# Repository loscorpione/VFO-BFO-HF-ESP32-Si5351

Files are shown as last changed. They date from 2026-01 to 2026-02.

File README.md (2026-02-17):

<h2 align="center">VFO/BFO con SI5351A ed ESP32</h2>

Questo progetto descrive la realizzazione di un VFO / BFO digitale
basato su ESP32 DevKit 32D e generatore di frequenza Si5351A.



Il sistema è stato progettato per applicazioni radioamatoriali,
in particolare per ricevitori HF autocostruiti, ma può essere
utilizzato anche in apparati sperimentali e RTX fino a circa 160 MHz.

Caratteristiche:
- Generazione VFO e BFO indipendenti
- Gestione modi: AM, LSB, USB, CW
- Controllo AGC e attenuatore
- Pitch regolabile del BFO
- S-meter digitale con memoria di picco
- Encoder meccanici e ottici
- Display TFT a colori
- Espansione I/O tramite PCF8574
- Memorizzazione configurazioni su EEPROM 24LC32
- Firmware modulare in C++
- Funzione di calibrazione del Si5351

Architettura codice:
Il codice è strutturato in modo modulare:

- VFO_BFO → gestione frequenze
- PLL → configurazione Si5351
- bands / modes → logica operativa
- DigiOUT → uscite digitali PCF8574
- s_meter → lettura analogica
- display → interfaccia grafica
- EEPROM_manager → salvataggio configurazioni

Il firmware è sviluppato con PlatformIO su VS Code.

Questa scelta permette:
- gestione strutturata del progetto
- controllo delle librerie
- maggiore scalabilità rispetto all’Arduino IDE

⚠️ Il firmware è in continua evoluzione.

I comandi sono:
- ENCODER 1: come selettore di frequenza.
- ENCODER 2: come variazione Pitch del BFO
- STEP: per cambio frequenza (10Hz, 100Hz, 1KHz, 10KHZ) con indicazione su display.
- BAND: per la selezione della banda con indicazione su display delle bande radioamatoriali e non.
- MODE: seleziona il tipo di demodulazione, con indicazione su pin binaria.
- AGC: slow e fast
- ATT: selettore attenuatore

<h2 align="center">🎬 Video del progetto</h2>

<p align="center">
  <a href="https://youtu.be/RLuy1z0uWSg">
    
  </a>
</p>

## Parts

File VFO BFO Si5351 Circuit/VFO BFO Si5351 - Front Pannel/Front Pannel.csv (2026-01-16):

Reference | Qty | Value | DNP | Exclude from BOM | Exclude from Board | Footprint | Datasheet
D1 | 1 | LED |  |  |  | LED_THT:LED_D3.0mm | ~
H1,H2,H3,H4 | 4 | MountingHole |  | Escluso dalla DIBA |  | MountingHole:MountingHole_3.2mm_M3_DIN965 | ~
J1 | 1 | LED |  |  |  | Connector_JST:JST_EH_B2B-EH-A_1x02_P2.50mm_Vertical | ~
J2 | 1 | Optical Rotary Encoder |  |  |  | Connector_JST:JST_EH_B4B-EH-A_1x04_P2.50mm_Vertical | ~
J3 | 1 | Mecc_rotary encoder |  |  |  | Connector_PinSocket_2.54mm:PinSocket_1x05_P2.54mm_Horizontal | ~
J4 | 1 | VFO_Front_Pannel |  |  |  | Connector_PinHeader_2.54mm:PinHeader_1x20_P2.54mm_Vertical | ~
R1 | 1 | R=Vled-2/20mA |  |  |  | Resistor_THT:R_Axial_DIN0207_L6.3mm_D2.5mm_P10.16mm_Horizontal | ~
R2,R3,R4 | 3 | 10K |  |  |  | Resistor_THT:R_Axial_DIN0207_L6.3mm_D2.5mm_P10.16mm_Horizontal | ~
SW1 | 1 | RotaryEncoder_Clarifier |  |  |  | -Rotary_Encoder:RotaryEncoder_Alps_EC12E-Switch_Vertical_H20mm | ~
SW2 | 1 | SW_Band |  |  |  | Button_Switch_THT:SW_PUSH_6mm | ~
SW3 | 1 | SW_Mode |  |  |  | Button_Switch_THT:SW_PUSH_6mm | ~
SW4 | 1 | SW_AGC |  |  |  | Button_Switch_THT:SW_PUSH_6mm | ~
SW5 | 1 | SW_ATT |  |  |  | Button_Switch_THT:SW_PUSH_6mm | ~
SW6 | 1 | SW_Scan |  |  |  | Button_Switch_THT:SW_PUSH_6mm | ~
SW7 | 1 | SW_Step |  |  |  | Button_Switch_THT:SW_PUSH_6mm | ~
SW8 | 1 | SW_RTTY_CW |  |  |  | Button_Switch_THT:SW_PUSH_6mm | ~
U1 | 1 | Ili9341_Module_TFT_320x240_Touch |  |  |  | -Display_Graphic:DISPLAY_TFT_ILI9341_2.8

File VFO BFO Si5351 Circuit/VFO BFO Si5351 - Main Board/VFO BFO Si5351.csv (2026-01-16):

Reference | Qty | Value | DNP | Exclude from BOM | Exclude from Board | Footprint | Datasheet
C1,C4 | 2 | 100nF |  |  |  | Capacitor_THT:C_Rect_L7.0mm_W2.5mm_P5.00mm | ~
C2 | 1 | 220uF 16V |  |  |  | Capacitor_THT:CP_Radial_D6.3mm_P2.50mm | ~
C3 | 1 | 100uF 10V |  |  |  | Capacitor_THT:CP_Radial_D5.0mm_P2.00mm | ~
D1 | 1 | 1N4148 |  |  |  | Diode_THT:D_DO-35_SOD27_P7.62mm_Horizontal | https://assets.nexperia.com/documents/data-sheet/1N4148_1N4448.pdf
D2,D3 | 2 | 3.3V |  |  |  | Diode_THT:D_DO-35_SOD27_P7.62mm_Horizontal | https://industrial.panasonic.com/content/data/SC/ds/ds4/DZ2S03300L_E.pdf
D4 | 1 | 1N4007 |  |  |  | Diode_THT:D_DO-41_SOD81_P10.16mm_Horizontal | http://www.vishay.com/docs/88503/1n4001.pdf
H1,H2,H3,H4 | 4 | MountingHole_Pad |  | Escluso dalla DIBA |  | MountingHole:MountingHole_3.2mm_M3_DIN965_Pad_TopBottom | ~
J1 | 1 | I2C Bus |  |  |  | Connector_JST:JST_EH_B4B-EH-A_1x04_P2.50mm_Vertical | ~
J2 | 1 | Band |  |  |  | Connector_JST:JST_EH_B4B-EH-A_1x04_P2.50mm_Vertical | ~
J3 | 1 | Mode |  |  |  | Connector_JST:JST_EH_B3B-EH-A_1x03_P2.50mm_Vertical | ~
J4 | 1 | AGC |  |  |  | Connector_JST:JST_EH_B2B-EH-A_1x02_P2.50mm_Vertical | ~
J5 | 1 | ATT |  |  |  | Connector_JST:JST_EH_B2B-EH-A_1x02_P2.50mm_Vertical | ~
J6 | 1 | BFO |  |  |  | Connector_JST:JST_EH_B2B-EH-A_1x02_P2.50mm_Vertical | ~
J7 | 1 | TX |  |  |  | Connector_JST:JST_EH_B2B-EH-A_1x02_P2.50mm_Vertical | ~
J8 | 1 | IN RTTY |  |  |  | Connector_JST:JST_EH_B2B-EH-A_1x02_P2.50mm_Vertical | ~
J9 | 1 | IN S_meter |  |  |  | Connector_JST:JST_EH_B2B-EH-A_1x02_P2.50mm_Vertical | ~
J10 | 1 | VIN +12V |  |  |  | Connector_JST:JST_EH_B2B-EH-A_1x02_P2.50mm_Vertical | ~
J11 | 1 | GND +5V +9V +12 |  |  |  | Connector_JST:JST_EH_B4B-EH-A_1x04_P2.50mm_Vertical | ~
J12 | 1 | VFO_Front_Pannel |  |  |  | Connector_PinHeader_2.54mm:PinHeader_1x20_P2.54mm_Vertical | ~
M1 | 1 | Si5351A module |  |  |  | -Periferial_Module:si5351a_Module
R1,R3 | 2 | 1K |  |  |  | Resistor_THT:R_Axial_DIN0207_L6.3mm_D2.5mm_P10.16mm_Horizontal | ~
RN1 | 1 | 10Kx8 |  |  |  | Resistor_THT:R_Array_SIP9 | http://www.vishay.com/docs/31509/csc.pdf
U1 | 1 | ESP32-DEVKITC-32D |  |  |  | -ESP32_Module:MODULE_ESP32-DEVKITC-32D
U2 | 1 | PCF8574AP |  |  |  | Package_DIP:DIP-16_W7.62mm | http://www.nxp.com/docs/en/data-sheet/PCF8574_PCF8574A.pdf
U3 | 1 | LM7809 |  |  |  | Package_TO_SOT_THT:TO-220-3_Vertical | https://www.onsemi.cn/PowerSolutions/document/MC7800-D.PDF
U4 | 1 | LM7805 |  |  |  | Package_TO_SOT_THT:TO-220-3_Vertical | https://www.onsemi.cn/PowerSolutions/document/MC7800-D.PDF
U5 | 1 | 24LC32 |  |  |  | Package_DIP:DIP-8_W7.62mm | http://ww1.microchip.com/downloads/en/DeviceDoc/21072G.pdf

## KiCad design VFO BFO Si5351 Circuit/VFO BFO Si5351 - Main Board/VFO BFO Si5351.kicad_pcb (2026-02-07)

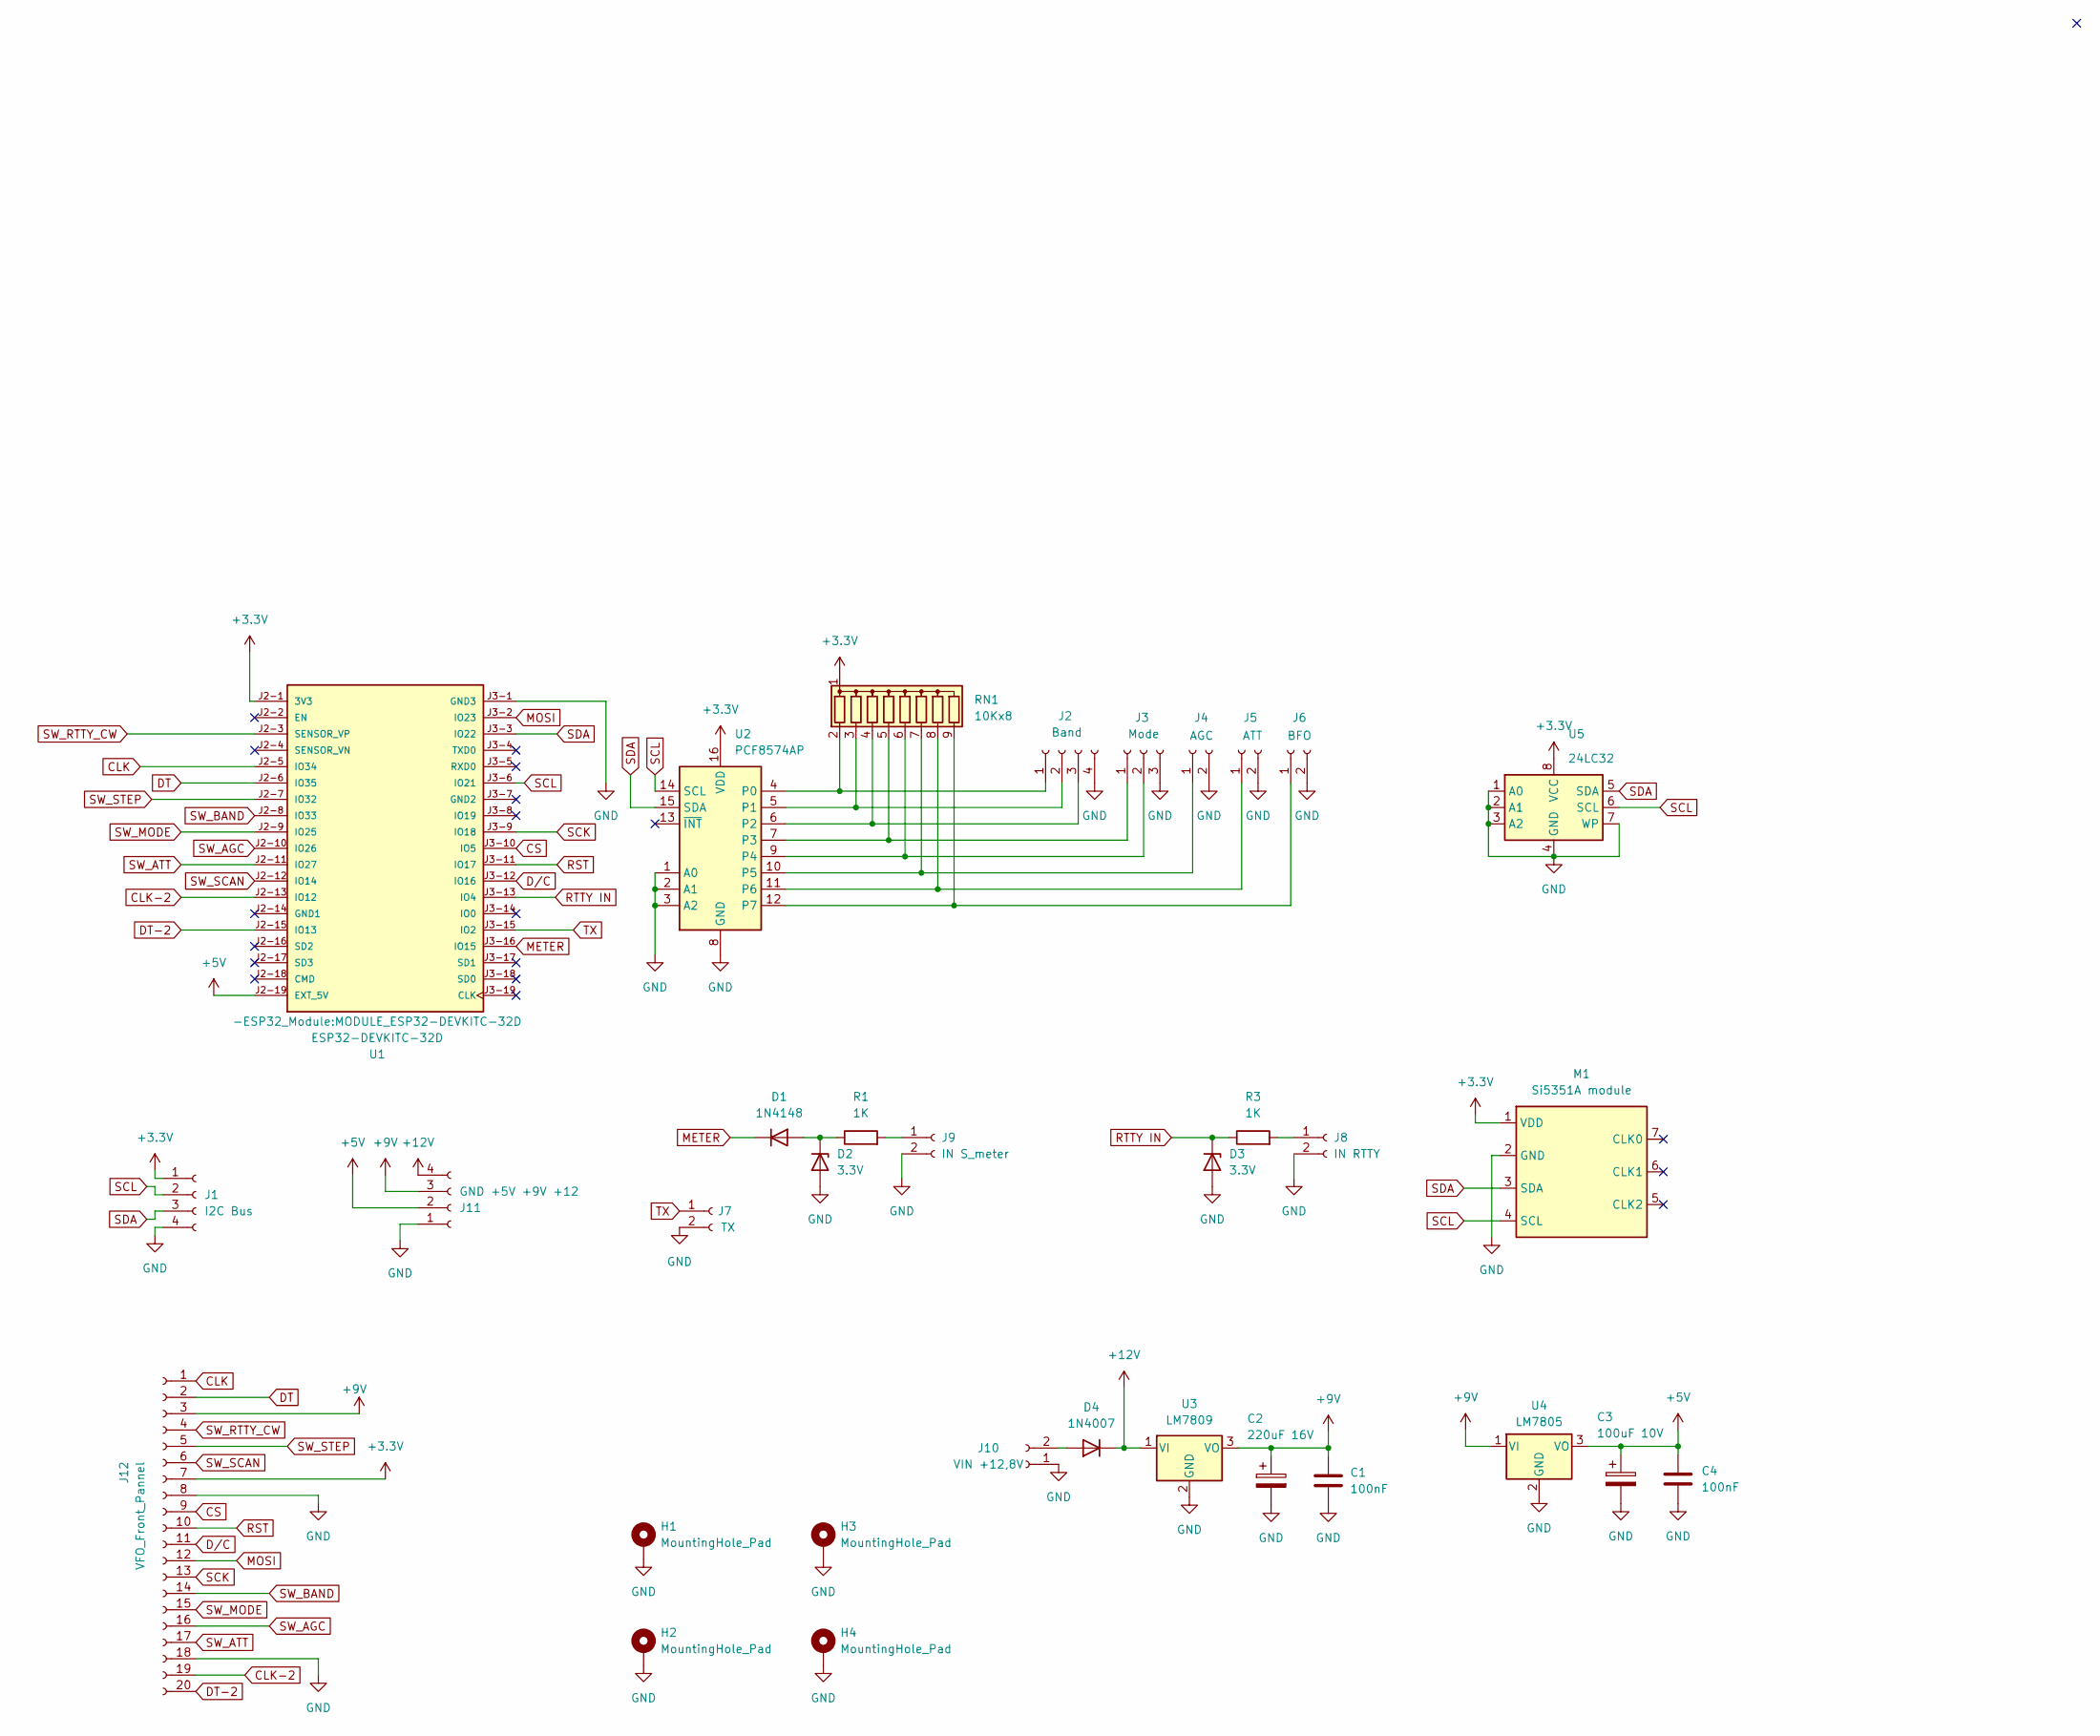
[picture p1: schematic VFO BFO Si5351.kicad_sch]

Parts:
C1, C4: 100nF; C_Rect_L7.0mm_W2.5mm_P5.00mm
C2: 220uF 16V; CP_Radial_D6.3mm_P2.50mm
C3: 100uF 10V; CP_Radial_D5.0mm_P2.00mm
D1: 1N4148; D_DO-35_SOD27_P7.62mm_Horizontal
D2, D3: 3.3V; D_DO-35_SOD27_P7.62mm_Horizontal
D4: 1N4007; D_DO-41_SOD81_P10.16mm_Horizontal
H1, H2, H3, H4: MountingHole_Pad; MountingHole_3.2mm_M3_DIN965_Pad_TopBottom
J1: I2C Bus; JST_EH_B4B-EH-A_1x04_P2.50mm_Vertical
J2: Band; JST_EH_B4B-EH-A_1x04_P2.50mm_Vertical
J3: Mode; JST_EH_B3B-EH-A_1x03_P2.50mm_Vertical
J4: AGC; JST_EH_B2B-EH-A_1x02_P2.50mm_Vertical
J5: ATT; JST_EH_B2B-EH-A_1x02_P2.50mm_Vertical
J6: BFO; JST_EH_B2B-EH-A_1x02_P2.50mm_Vertical
J7: TX; JST_EH_B2B-EH-A_1x02_P2.50mm_Vertical
J8: IN RTTY; JST_EH_B2B-EH-A_1x02_P2.50mm_Vertical
J9: IN S_meter; JST_EH_B2B-EH-A_1x02_P2.50mm_Vertical
J10: VIN +12,8V; JST_EH_B2B-EH-A_1x02_P2.50mm_Vertical
J11: GND +5V +9V +12; JST_EH_B4B-EH-A_1x04_P2.50mm_Vertical
J12: VFO_Front_Pannel; PinHeader_1x20_P2.54mm_Vertical
M1: Si5351A module; si5351a_Module
R1, R3: 1K; R_Axial_DIN0207_L6.3mm_D2.5mm_P10.16mm_Horizontal
RN1: 10Kx8; R_Array_SIP9
U1: ESP32-DEVKITC-32D; MODULE_ESP32-DEVKITC-32D; PARTREV V4
U2: PCF8574AP; DIP-16_W7.62mm
U3: LM7809; TO-220-3_Vertical
U4: LM7805; TO-220-3_Vertical
U5: 24LC32; DIP-8_W7.62mm

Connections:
+3.3V: J1.1, J12.7, M1.1 (VDD), RN1.1 (common), U1.J2-1 (3V3), U2.16 (VDD), U5.8 (VCC)
+5V: C3.1, C4.1, J11.2, U1.J2-19 (EXT_5V), U4.3 (VO)
+9V: C1.1, C2.1, J11.3, J12.3, U3.3 (VO), U4.1 (VI)
+12V: D4.1 (K), J11.4, U3.1 (VI)
CLK: J12.1, U1.J2-5 (IO34)
CLK-2: J12.19, U1.J2-13 (IO12)
CS: J12.9, U1.J3-10 (IO5)
DT: J12.2, U1.J2-6 (IO35)
DT-2: J12.20, U1.J2-15 (IO13)
D/C: J12.11, U1.J3-12 (IO16)
GND: C1.2, C2.2, C3.2, C4.2, D2.2 (A), D3.2 (A), H1.1, H2.1, H3.1, H4.1, J1.4, J2.4, J3.3, J4.2, J5.2, J6.2, J7.2, J8.2, J9.2, J10.1, J11.1, J12.8, J12.18, M1.2 (GND), U1.J3-1 (GND3), U2.1 (A0), U2.2 (A1), U2.3 (A2), U2.8 (GND), U3.2 (GND), U4.2 (GND), U5.1 (A0), U5.2 (A1), U5.3 (A2), U5.4 (GND), U5.7 (WP)
METER: D1.1 (K), U1.J3-16 (IO15)
MOSI: J12.12, U1.J3-2 (IO23)
unnamed: D1.2 (A), D2.1 (K), R1.1
unnamed: D4.2 (A), J10.2
unnamed: J2.1, RN1.2 (R1), U2.4 (P0)
unnamed: J2.2, RN1.3 (R2), U2.5 (P1)
unnamed: J2.3, RN1.4 (R3), U2.6 (P2)
unnamed: J3.1, RN1.5 (R4), U2.7 (P3)
unnamed: J3.2, RN1.6 (R5), U2.9 (P4)
unnamed: J4.1, RN1.7 (R6), U2.10 (P5)
unnamed: J5.1, RN1.8 (R7), U2.11 (P6)
unnamed: J6.1, RN1.9 (R8), U2.12 (P7)
unnamed: J8.1, R3.2
unnamed: J9.1, R1.2
RST: J12.10, U1.J3-11 (IO17)
RTTY IN: D3.1 (K), R3.1, U1.J3-13 (IO4)
SCK: J12.13, U1.J3-9 (IO18)
SCL: J1.2, M1.4 (SCL), U1.J3-6 (IO21), U2.14 (SCL), U5.6 (SCL)
SDA: J1.3, M1.3 (SDA), U1.J3-3 (IO22), U2.15 (SDA), U5.5 (SDA)
SW_AGC: J12.16, U1.J2-10 (IO26)
SW_ATT: J12.17, U1.J2-11 (IO27)
SW_BAND: J12.14, U1.J2-8 (IO33)
SW_MODE: J12.15, U1.J2-9 (IO25)
SW_RTTY_CW: J12.4, U1.J2-3 (SENSOR_VP)
SW_SCAN: J12.6, U1.J2-12 (IO14)
SW_STEP: J12.5, U1.J2-7 (IO32)
TX: J7.1, U1.J3-15 (IO2)

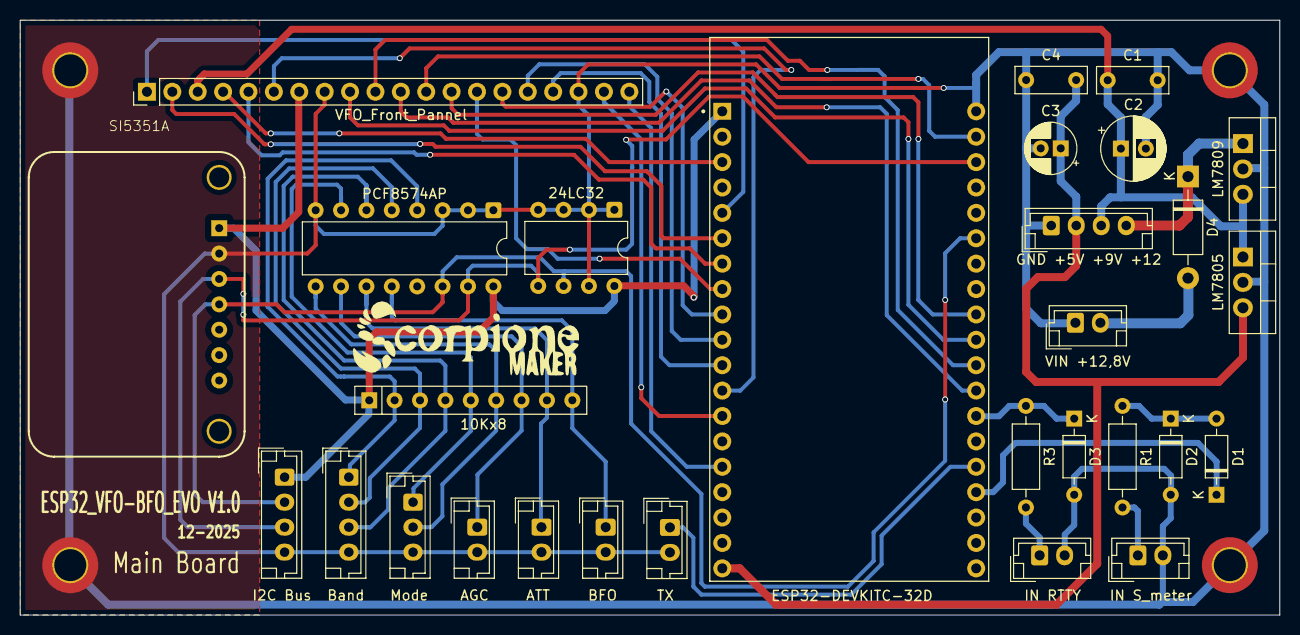
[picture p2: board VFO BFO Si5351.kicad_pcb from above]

Board: 2 copper layers, 126.0 x 59.5 mm, 33 parts (0 on the bottom side), 38 nets.

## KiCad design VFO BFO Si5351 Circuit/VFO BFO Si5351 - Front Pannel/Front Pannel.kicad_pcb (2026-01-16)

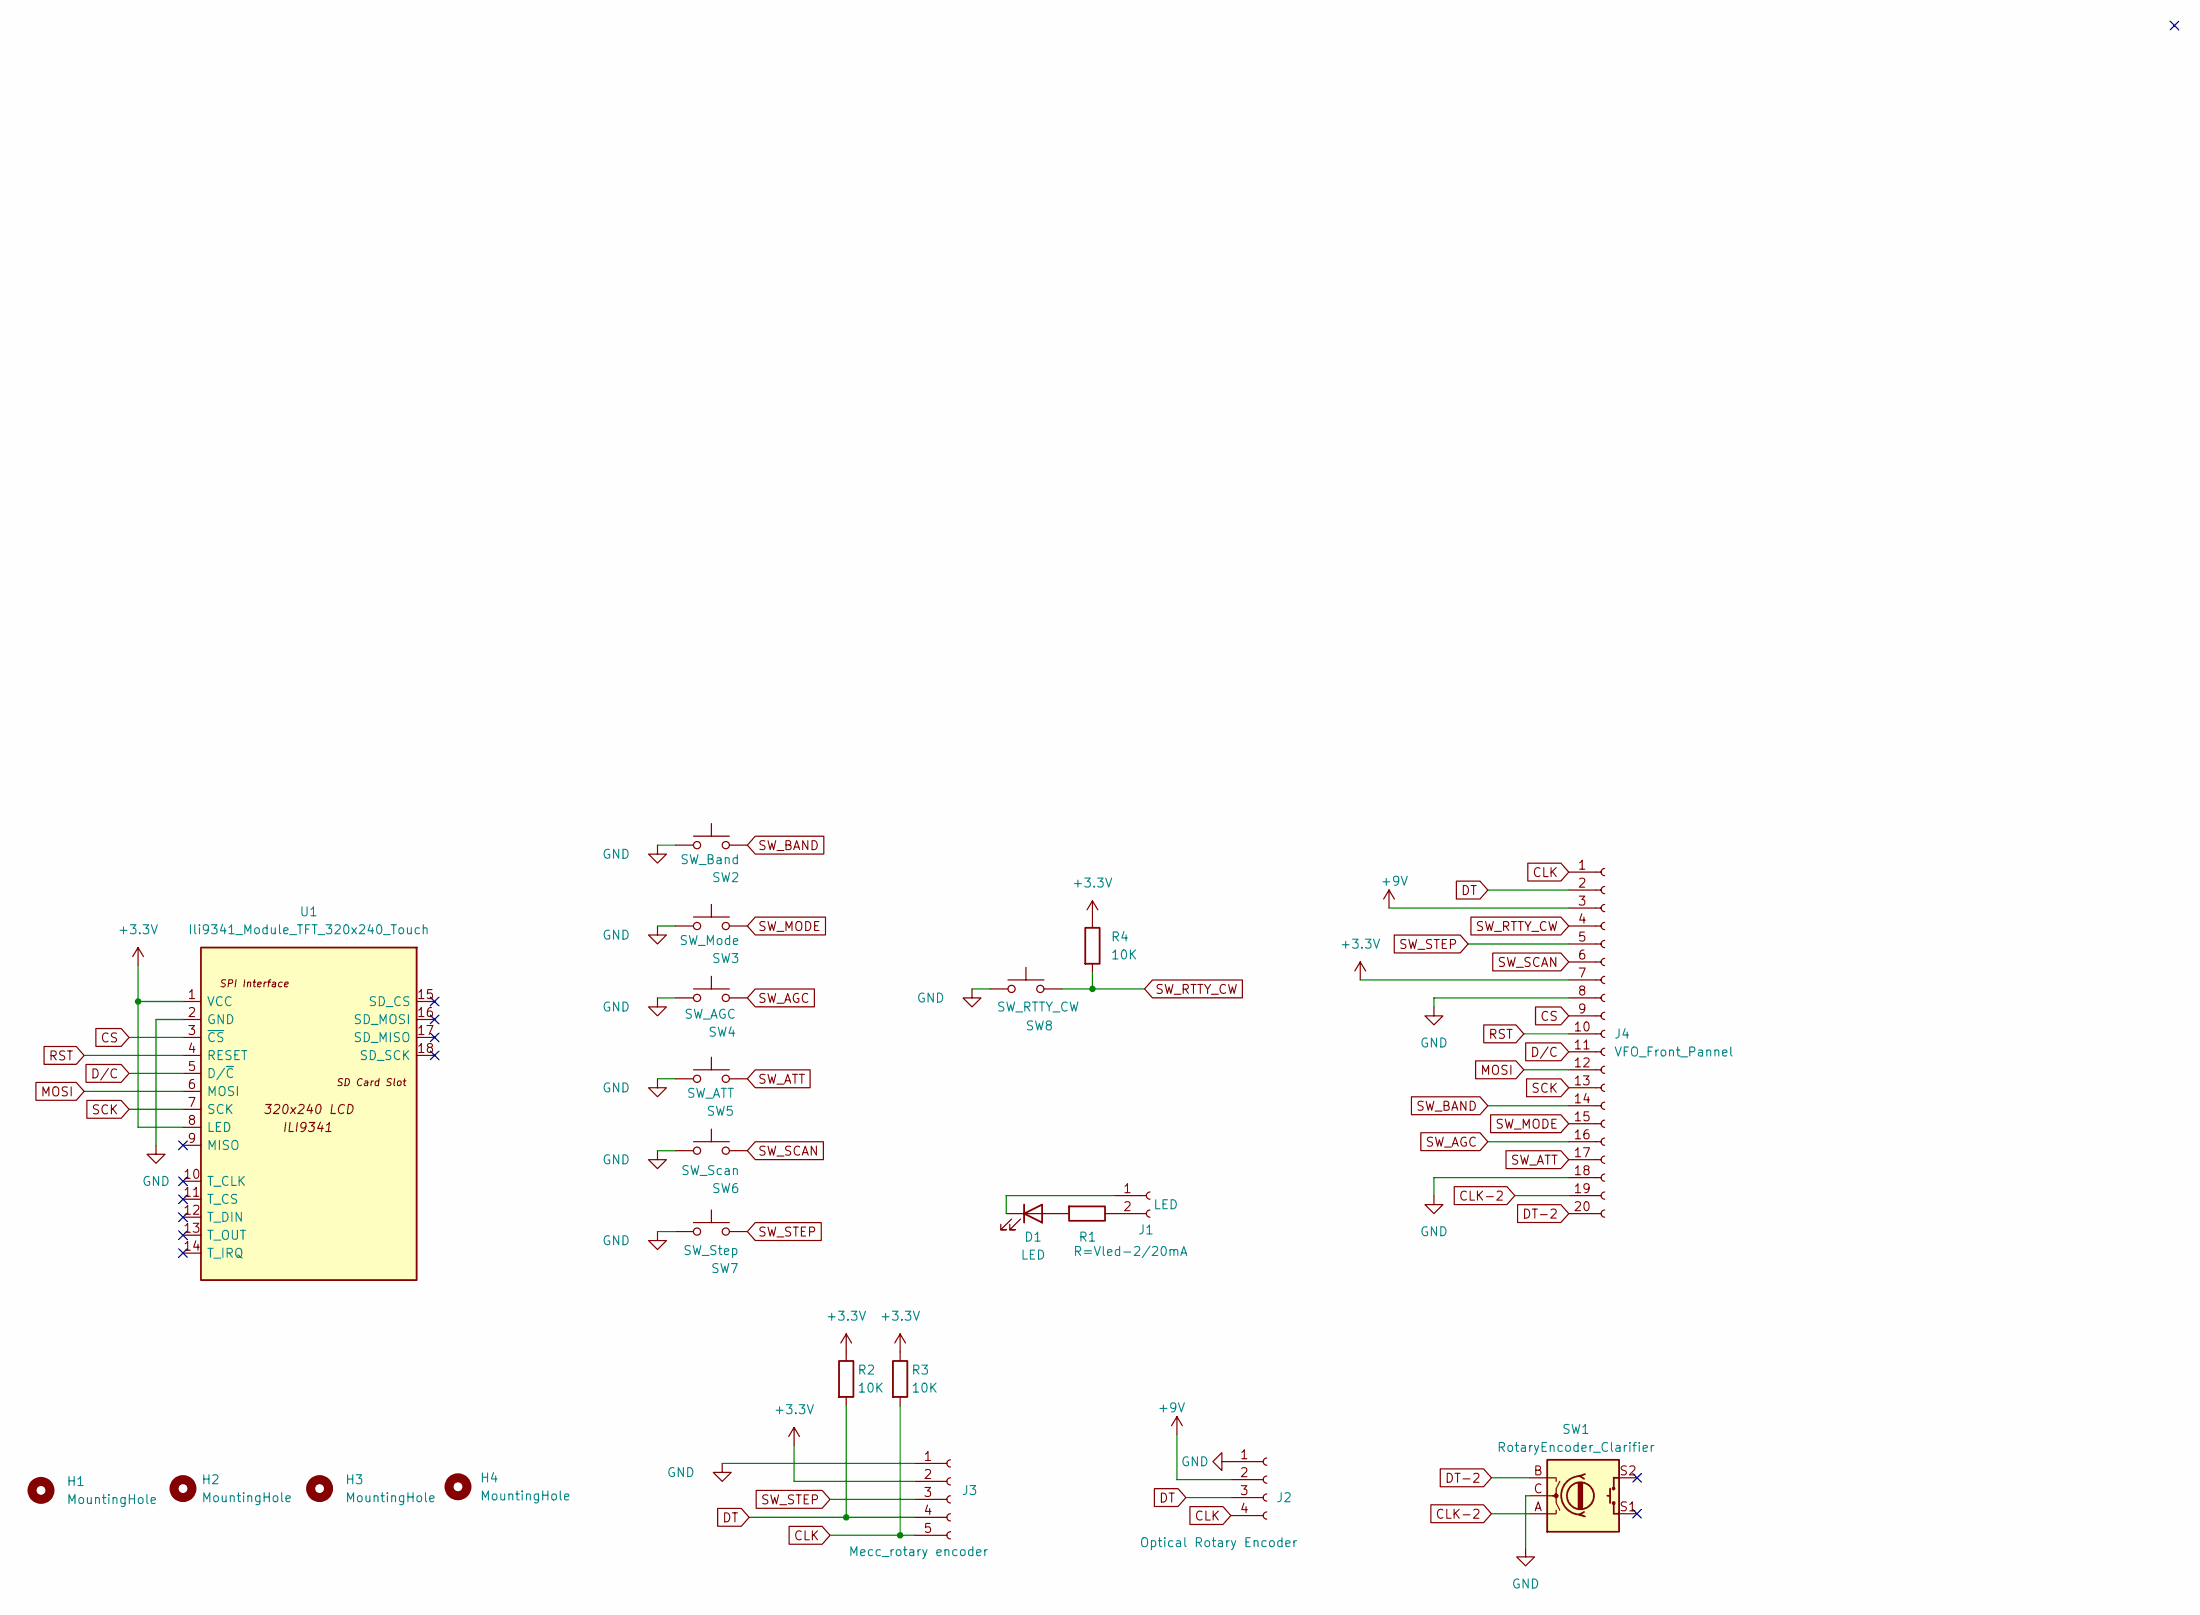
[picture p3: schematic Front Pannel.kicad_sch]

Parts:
D1: LED; LED_D3.0mm
H1, H2, H3, H4: MountingHole; MountingHole_3.2mm_M3_DIN965
J1: LED; JST_EH_B2B-EH-A_1x02_P2.50mm_Vertical
J2: Optical Rotary Encoder; JST_EH_B4B-EH-A_1x04_P2.50mm_Vertical
J3: Mecc_rotary encoder; PinSocket_1x05_P2.54mm_Horizontal
J4: VFO_Front_Pannel; PinHeader_1x20_P2.54mm_Vertical
R1: R=Vled-2/20mA; R_Axial_DIN0207_L6.3mm_D2.5mm_P10.16mm_Horizontal
R2, R3, R4: 10K; R_Axial_DIN0207_L6.3mm_D2.5mm_P10.16mm_Horizontal
SW1: RotaryEncoder_Clarifier; RotaryEncoder_Alps_EC12E-Switch_Vertical_H20mm
SW2: SW_Band; SW_PUSH_6mm
SW3: SW_Mode; SW_PUSH_6mm
SW4: SW_AGC; SW_PUSH_6mm
SW5: SW_ATT; SW_PUSH_6mm
SW6: SW_Scan; SW_PUSH_6mm
SW7: SW_Step; SW_PUSH_6mm
SW8: SW_RTTY_CW; SW_PUSH_6mm
U1: Ili9341_Module_TFT_320x240_Touch; DISPLAY_TFT_ILI9341_2.8

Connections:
+3.3V: J3.2, J4.7, R2.1, R3.1, R4.1, U1.1 (VCC), U1.8 (LED)
+9V: J2.2, J4.3
CLK: J2.4, J3.5, J4.1, R3.2
CLK-2: J4.19, SW1.A
CS: J4.9, U1.3 (~CS)
DT: J2.3, J3.4, J4.2, R2.2
DT-2: J4.20, SW1.B
D/C: J4.11, U1.5 (D/~C)
GND: J2.1, J3.1, J4.8, J4.18, SW1.C, SW2.1, SW3.1, SW4.1, SW5.1, SW6.1, SW7.1, SW8.1, U1.2 (GND)
MOSI: J4.12, U1.6 (MOSI)
unnamed: D1.2 (A), R1.2
unnamed: D1.1 (K), J1.1
unnamed: J1.2, R1.1
RST: J4.10, U1.4 (RESET)
SCK: J4.13, U1.7 (SCK)
SW_AGC: J4.16, SW4.2
SW_ATT: J4.17, SW5.2
SW_BAND: J4.14, SW2.2
SW_MODE: J4.15, SW3.2
SW_RTTY_CW: J4.4, R4.2, SW8.2
SW_SCAN: J4.6, SW6.2
SW_STEP: J3.3, J4.5, SW7.2

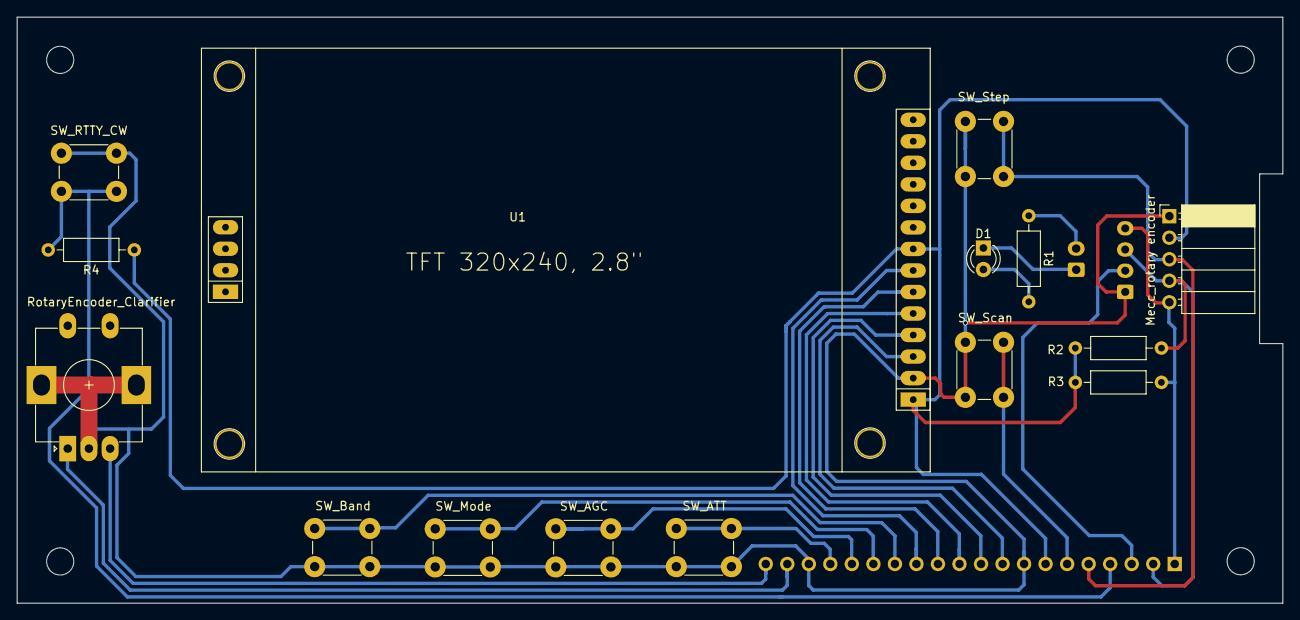
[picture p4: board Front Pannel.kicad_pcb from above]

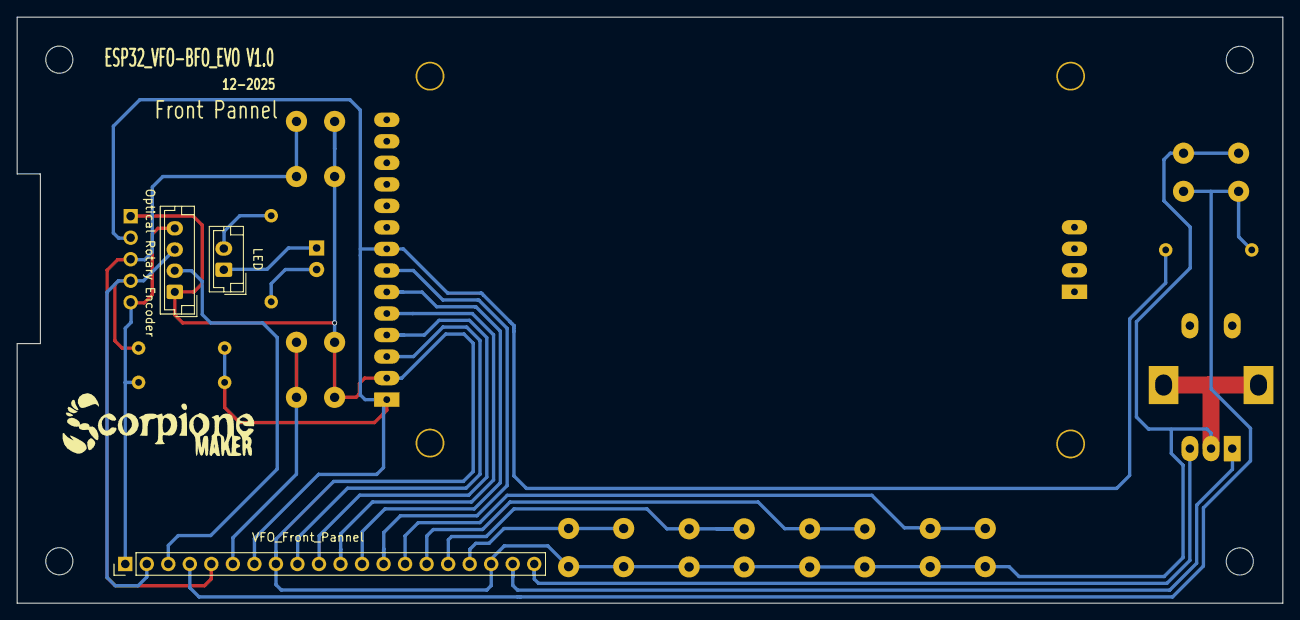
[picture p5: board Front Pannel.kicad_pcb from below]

Board: 2 copper layers, 149.4 x 69.2 mm, 22 parts (3 on the bottom side), 22 nets.

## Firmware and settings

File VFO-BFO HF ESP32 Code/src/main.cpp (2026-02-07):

#include <Arduino.h>
#include "config.h"
#include "display.h"
#include "VFO_BFO.h"
#include "PLL.h"
#include "bands.h"
#include "modes.h"
#include "s_meter.h"
#include "DigiOUT.h" 
#include "functions.h"
#include "EEPROM_manager.h"

void handleSerialCommands();
void calibrateSI5351(long calibration_factor); // Dichiarazione

// Variabile per calibrazione - AGGIUNGI
int32_t currentCalibration = 0;

// Variabili globali
unsigned long vfoFrequency = 7000000 + IF_FREQUENCY;
unsigned long displayedFrequency = 7000000;
unsigned long step = 1000;
unsigned long minFreq = 1000000;
unsigned long maxFreq = 30000000;

// Variabili per debounce
unsigned long lastEncoderRead = 0;
const int encoderReadInterval = 10;
unsigned long lastButtonPress = 0;
unsigned long lastBandButtonPress = 0;
unsigned long lastModeButtonPress = 0;

bool buttonPressed = false;
bool bandButtonPressed = false;
bool modeButtonPressed = false;

// Variabili encoder
int lastEncoded = 0;
int encoderCount = 0;

// Funzione per gestire comandi seriali
void handleSerialCommands() {
    if (Serial.available() > 0) {
        String command = Serial.readStringUntil('\n');
        command.trim();
        
        if (command.startsWith("CAL ")) {
            // Comando: CAL <valore>
            String valueStr = command.substring(4);
            long calValue = valueStr.toInt();
            
            calibrateSI5351(calValue);
            eepromManager.saveCalibration(calValue);
            currentCalibration = calValue;
            
            Serial.print("Calibrazione applicata e salvata: ");
            Serial.println(calValue);
            
        } else if (command == "CAL_READ") {
            // Legge calibrazione corrente
            Serial.print("Calibrazione corrente: ");
            Serial.println(currentCalibration);
            
        } else if (command == "CAL_RESET") {
            // Resetta calibrazione
            calibrateSI5351(0);
            eepromManager.saveCalibration(0);
            currentCalibration = 0;
            Serial.println("Calibrazione resettata a 0");
            
        } else if (command == "HELP") {
            // Mostra aiuto
            Serial.println("Comandi calibrazione SI5351:");
            Serial.println("CAL <valore>  - Imposta calibrazione (es: CAL 1250)");
            Serial.println("CAL_READ      - Legge calibrazione corrente");
            Serial.println("CAL_RESET     - Resetta calibrazione a 0");
            Serial.println("HELP          - Mostra questo aiuto");
            Serial.println("INFO          - Informazioni sistema");
            
        } else if (command == "INFO") {
            // Informazioni sistema
            Serial.println("=== VFO-BFO Receiver ===");
            Serial.print("Frequenza: ");
            Serial.print(displayedFrequency);
            Serial.println(" Hz");
            Serial.print("Modalità: ");
            Serial.println(modeNames[currentMode]);
            Serial.print("Step: ");
            Serial.println(step);
            Serial.print("Calibrazione SI5351: ");
            Serial.println(currentCalibration);
            Serial.print("BFO: ");
            Serial.println(bfoEnabled ? "ON" : "OFF");
            if (bfoEnabled) {
                Serial.print("Frequenza BFO: ");
                Serial.println(bfoFrequency);
            }
        }
    }
}

void setup() {
  Serial.begin(115200);
  delay(1000);

/*   //**********************************************************
  // // === DIAGNOSTICA I2C ===
  Serial.println("\n=== DIAGNOSTICA I2C ===");
  Wire.begin(I2C_SDA, I2C_SCL);
  Wire.setClock(100000); // 100kHz
  delay(100);
  
  // Scansiona tutto il bus I2C
  byte error, address;
  int nDevices = 0;
  
  Serial.println("Scansione bus I2C...");
  for(address = 1; address < 127; address++) {
    Wire.beginTransmission(address);
    error = Wire.endTransmission();
    
    if (error == 0) {
      Serial.print("Dispositivo trovato all'indirizzo 0x");
      if (address < 16) Serial.print("0");
      Serial.print(address, HEX);
      
      // Identifica i dispositivi
      if (address == 0x60) Serial.println(" -> SI5351");
      else if (address == 0x20) Serial.println(" -> PCF8574A");
      else if (address == 0x50) Serial.println(" -> EEPROM 24LC32");
      else Serial.println(" -> Sconosciuto");
      
      nDevices++;
    }
  }
  
  if (nDevices == 0) {
    Serial.println("Nessun dispositivo I2C trovato!");
  } else {
    Serial.print("Totale dispositivi trovati: ");
    Serial.println(nDevices);
  }
  Serial.println("=== FINE DIAGNOSTICA ===\n");
  //********************************************************** */

  // Configurazione encoder VFO con pull-up interni 
  pinMode(VFO_ENC_CLK, INPUT_PULLUP);
  pinMode(VFO_ENC_DT, INPUT_PULLUP);
  pinMode(SW_STEP, INPUT_PULLUP);

  // Configurazione I2C con pull-up interni 
  // pinMode(I2C_SDA, INPUT_PULLUP);
  // pinMode(I2C_SCL, INPUT_PULLUP);

  // Configura encoder pitch BFO con pull-up interni 
  pinMode(BFO_ENC_CLK, INPUT_PULLUP);
  pinMode(BFO_ENC_DT, INPUT_PULLUP);

  // Configura pulsanti con pull-up interni 
  pinMode(SW_AGC, INPUT_PULLUP);
  pinMode(SW_ATT, INPUT_PULLUP);
  pinMode(SW_BAND, INPUT_PULLUP);
  pinMode(SW_MODE, INPUT_PULLUP);
  pinMode(SW_SCAN, INPUT_PULLUP);

  // Inizializza I2C con clock ridotto PRIMA di tutto
  Wire.begin(I2C_SDA, I2C_SCL);
  Wire.setClock(400000); //  400kHz

  // Inizializza display
  tft.init();
  tft.setRotation(1);
  tft.fillScreen(BACKGROUND_COLOR);

  // Inizializza EEPROM e carica configurazione
  eepromManager.begin();
  eepromManager.loadRXState();

  long savedCalibration = 0;
  if (eepromManager.loadCalibration(savedCalibration)) {
      calibrateSI5351(savedCalibration);
  }
  // Calcola vfoFrequency
  vfoFrequency = displayedFrequency + IF_FREQUENCY;

  // Inizializza encoder
  setupEncoders();
  
  // Inizializza DigiOUT
  setupDigiOUT();

  // Inizializza SI5351
  setupSI5351();

  // Disegna layout del display
  drawDisplayLayout(); 

  // Aggiorna tutti i display
  updateFrequencyDisplay();
  updateFrequency();
  updateStepDisplay();
  updateModeInfo();
  updateModeOutputs();
  updateBandInfo();
  updateAGCDisplay();
  updateATTDisplay();

  // Informazioni per calibrazione via seriale
  Serial.println("VFO-BFO Ready - Invio 'HELP' per comandi calibrazione");
}

void loop() {
  readVFOEncoder();

  // Gestione Pitch BFO
  static int lastBFOOffset = 0;
  updateBFOFromEncoder();
  
  if (currentBFOOffset != lastBFOOffset) {
    drawBFODisplay();
    lastBFOOffset = currentBFOOffset;
  }

  // Gestione comandi seriali
  handleSerialCommands();

  // Gestione pulsante step
  if (digitalRead(SW_STEP) == LOW && !buttonPressed) {
    if (millis() - lastButtonPress > buttonDebounce) {
      buttonPressed = true;
      changeStep();
      lastButtonPress = millis();
      updateStepDisplay();
      eepromManager.requestQuickSave();
      delay(300);
    }
  }  
  if (digitalRead(SW_STEP) == HIGH && buttonPressed) {
    buttonPressed = false;
  }

  // Gestione pulsante banda
  if (digitalRead(SW_BAND) == LOW && !bandButtonPressed) {
    if (millis() - lastBandButtonPress > buttonDebounce) {
      bandButtonPressed = true;
      changeBand();
      lastBandButtonPress = millis();
      updateFrequency();
      updateFrequencyDisplay();
      updateBandInfo();
      eepromManager.requestQuickSave();
      delay(300);
    }
  } 
  if (digitalRead(SW_BAND) == HIGH && bandButtonPressed) {
    bandButtonPressed = false;
  }

  // Gestione pulsante modalità
  if (digitalRead(SW_MODE) == LOW && !modeButtonPressed) {
    if (millis() - lastModeButtonPress > buttonDebounce) {
      modeButtonPressed = true;
      changeMode();
      lastModeButtonPress = millis();
      updateModeOutputs();
      updateModeInfo();
      eepromManager.requestQuickSave();
      delay(300);
    }
  } 
  if (digitalRead(SW_MODE) == HIGH && modeButtonPressed) {
    modeButtonPressed = false;
  }

  // Gestione pulsante AGC
  checkAGCButton();

  // Gestione pulsante ATT
  checkATTButton();

  // Aggiorna S-meter ogni 50ms
  static unsigned long lastSMeterUpdate = 0;
  if (millis() - lastSMeterUpdate > 50) {
    updateSMeter();
    lastSMeterUpdate = millis();
  }

  // Gestione salvataggio EEPROM
  eepromManager.update();
}

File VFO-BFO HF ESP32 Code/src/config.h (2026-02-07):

#ifndef CONFIG_H
#define CONFIG_H


// Configurazione GPIO Encoder
#define VFO_ENC_CLK 34                  // Pin CLK dell'encoder VFO
#define VFO_ENC_DT  35                  // Pin DT dell'encoder VFO
#define BFO_ENC_CLK 12                  // Pin CLK dell'encoder BFO
#define BFO_ENC_DT  13                  // Pin DT dell'encoder BFO

// Configurazione GPIO Pulsanti
    #define SW_STEP 32                  // Pulsante cambio Step VFO
    #define SW_BAND 33                  // Pulsante cambio banda
    #define SW_MODE 25                  // Pulsante cambio modalità
    #define SW_AGC  26                  // Pulsante AGC Fast/Slow
    #define SW_ATT  27                  // Pulsante Attenuatore -20dB
    #define SW_SCAN 14                  // Pulsante Scan (futuro)
    #define SW_RTTY_CW  36              // Pulsante RTTY_CW (futuro)

// Configurazione GPIO Ingresso S-Meter 
    #define S_METER_PIN 15              // Pin analogico per il S-meter
    #define RTTY_CW_PIN 4               // Pin digitale per RTTY_CW (futuro)

// Configurazione GPIO bus I2C 
    #define I2C_SCL 21                  // Pin SCL I2C
    #define I2C_SDA 22                  // Pin SDA I2C

// Indirizzo I2C del PCF8574A
    #define PCF8574A_ADDRESS 0x20       // indirizzo PCF8574 (A0,A1,A2 collegati a GND)

// Pin PCF8574A per codifica binaria
    #define PCF_MODE_BIT0  P0           // Pin P0 del PCF8574
    #define PCF_MODE_BIT1  P1           // Pin P1 del PCF8574
    #define PCF_MODE_BIT2  P2           // Pin P2 del PCF8574
    #define PCF_MODE_BIT3  P3           // Pin P3 del PCF8574
    #define PCF_MODE_BIT4  P4           // Pin P4 del PCF8574
    #define PCF_MODE_BIT5  P5           // Pin P5 del PCF8574
    #define PCF_MODE_BIT6  P6           // Pin P6 del PCF8574
    #define PCF_MODE_BIT7  P7           // Pin P7 del PCF8574 

// Indirizzo I2C della 24LC32
    #define EXTERNAL_EEPROM_ADDRESS 0x50// Indirizzo EEPROM esterna (A0,A1,A2 collegati a GND)

// Dimensione EEPROM in byte
    //#define EEPROM_SIZE 4096          // 24LC32 = 2Kbit = 4KB
    //#define EEPROM_SIZE 16384         // 24LC128 = 128Kbit = 16KB
    #define EEPROM_SIZE 32768           // 24LC256 = 256Kbit = 32KB

// Timing salvataggio
    #define EEPROM_SAVE_DELAY 3000      // Salva dopo 3 secondi di inattività
    #define EEPROM_QUICK_SAVE_DELAY 500 // Salvataggio rapido per cambi importanti


// Frequenza IF del ricevitore
    #define IF_FREQUENCY 455000         // IF=455kHz

// Display VFO
    #define VFO_DISPLAY_X 15            // Posizione X del display VFO
    #define VFO_DISPLAY_Y 30            // Posizione Y del display VFO
    #define VFO_LABEL_SIZE 2
    #define VFO_LABEL_COLOR TFT_SKYBLUE

// Frequenze BFO base (con offset di 1.5kHz)
    #define BFO_USB_BASE 453500         // BFO per USB (IF 455kHz - offset 1.5kHz)
    #define BFO_LSB_BASE 456500         // BFO per LSB (IF 455kHz + offset 1.5kHz)
    #define BFO_CW_BASE 454300          // BFO per CW (IF 455kHz - offset 700Hz) 

// Limiti Pitch BFO         
    #define BFO_PITCH_MIN -200          // -200Hz
    #define BFO_PITCH_MAX 200           // +200Hz  
    #define BFO_PITCH_STEP 5            // 5Hz per click

// Display BFO
    #define BFO_DISPLAY_X 80            // Posizione X del display BFO
    #define BFO_DISPLAY_Y 98            // Posizione Y del display BFO
    #define BFO_DISPLAY_WIDTH 120       // Larghezza display BFO
    #define BFO_DISPLAY_HEIGHT 40       // Altezza display BFO
    #define BFO_GRAPH_WIDTH 100         // Larghezza grafico
    #define BFO_GRAPH_HEIGHT 12         // Altezza grafico
    #define BFO_GRAPH_X 73              // Posizione X grafico
    #define BFO_GRAPH_Y 115             // Posizione Y grafico
    #define BFO_MARKER_HEIGHT 10        // Altezza linea verticale
    #define BFO_CENTER_MARKER_HEIGHT 12 // Altezza marcatore centrale
    #define BFO_LABEL_COLOR TFT_SKYBLUE // Colore etichetta BFO

// Display STEP
    #define STEP_BOX_X 250
    #define STEP_BOX_Y 102
    #define STEP_BOX_WIDTH 70
    #define STEP_BOX_HEIGHT 40
    #define STEP_BOX_TEXT_COLOR TFT_RED
    #define STEP_BOX_TEXT_SIZE 1

// S-Meter - Pin e configurazione 
    #define S_METER_X 15                // Posizione X
    #define S_METER_Y 160               // Posizione Y
    #define S_METER_WIDTH 300           // Larghezza totale
    #define S_METER_HEIGHT 15           // Altezza
    #define S_METER_SEGMENTS 25         // Numero di segmenti
    #define S_METER_SEGMENT_WIDTH 12    // Larghezza di ogni segmento

// Colori S-meter
    #define S_METER_LOW_COLOR TFT_GREEN
    #define S_METER_HIGH_COLOR TFT_RED
    #define S_METER_BG_COLOR TFT_DARKGREY
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

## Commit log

2026-01-16 ultimato PCB
    [Front Pannel.csv, Front Pannel.kicad_pcb, VFO BFO Si5351.csv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]
2026-02-07 Mod code end PCB
    Schema elettrico Main-board and Front-panel correzione impronta SI5351 e PCB
    Pulizia Codice ed implementazione out digitale BFO
    [VFO BFO Si5351.kicad_pcb, VFO BFO Si5351.kicad_sch]
2026-02-13 Modifiche al PCB
    [Front Pannel.kicad_sch, VFO BFO Si5351.kicad_sch]
2026-10-24 -cambio modalità USB/LSB automatico in base alla frequenza (solo per LSB/USB) -limitato il cambio di modalità automatico per AM e CW (non cambia mai) -limite step minimo a 10Hz e massimo a 10kHz per 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
